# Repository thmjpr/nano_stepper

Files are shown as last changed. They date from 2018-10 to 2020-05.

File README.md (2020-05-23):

# Notes
This is a modication of the nano zero stepper.

Hardware changes

Rev 1:
- Board re-layout
- Connectors optimized for simplicity/cost
- Input protection added (fuse and TVS)
- 12-36V step down section added
- Inputs are over/under voltage protected (high = 2~24V). No external supply connection needed (w/ level shifter). Tested to 90kHz step speed, limited by firmware. Not opto.
- Error out open collector

Rev 2:
- Add motor voltage monitor analog input (0 to 33V range)
- Add NTC resistor to measure motor driver temperature
- Remove JTAG header
- Adjust switch footprint

Rev 3:
- Change motor driver to A4950
- Change micro to SAMD51G18A
- Nema17/23 layouts
- Remove unused parts

# Photos

Rev2:



Rev1:
board
board2

Original project:

# Smart Stepper (also known as the nano zero stepper)
Firmware to turn a stepper motor into servo motor: see http://misfittech.net for hardware! 

If you want to support the work on the firmware and hardware consider buying hardware from www.misfittech.net or buying me a beer using the donation button. 



# How to Install 
[Hardware install](http://misfittech.net/2016/11/29/installing-the-nano-zero-stepper/)

[Arduino install] (http://misfittech.net/2016/07/27/arduino_install/) for building firmware

[Further Details and to purchase Hardware] (http://misfittech.net/product/nano-zero-stepper/)

# Command List

## Smart Stepper Command Line Interface
The smart stepper uses a command line interface where the prompt is “:>” 

### help 
The help command will return a list of commands that the smart stepper supports. 

### getcal
This command will print out the 200 point calibration table.  This is useful if you are doing firmware development and do not want to calibrate each time you update firmware.  You can take this table and copy it into the nonvolatile.cpp file as shown below

### calibrate
This will run a 200 point calibration of the encoder. 

### testcal 
This will test the calibration and report the maximum error in degrees. 

### step
This will move the motor one step clockwise, the step size is based on the current microstep setting.  To move the motor counterclockwise use “step 1”. To move the motor clockwise 16 steps used “step 0 16” to move motor counterclockwise 16 steps use “step 1 16”

### feedback 
This commands disable/enables feedback control loop. 
The plan is to discountinue this command in the future and use the “controlmode” command to put controller in open or one of the many closed loop operational modes. 

### readpos
Reads the current motor position and reports it as degrees.

### encoderdiag
This command will read and report the AS5047D internal registers for diagnostic purposes. 

### microsteps 
This command gets/sets the number of microsteps the smart stepper will use for the step command and the step pin.  The number of microsteps does not affect the resolution of the controller but rather how fine you can set the position. 

### spid
This command sets the Kp, Ki, and Kd terms for the simple positional PID controller. 

### ppid
This command sets the Kp, Ki, and Kd terms for the positional PID controller. 

### vpid
This command sets the Kp, Ki, and Kd terms for the velocity PID controller. 

### velocity 
This sets the velocity to rotate motor when unit is configured for velocity PID mode of operation. 

### boot
This command will put the microprocessor in the boot loader mode.  Alternatively this can be done by double pressing the reset button. 

### factoryreset 
This erases the calibration and other system and motor parameters such that unit is reset to the factory ship state.  After this command the unit will need to be calibrated to the motor again. 

### dirpin
This command sets which direction the motor will rotate when direction pin is pulled high. The direction pin is only sampled when the step pin has a rising edge. 
‘dirpin 0’ will set the motor to rotate clockwise when dir pin is high
‘dirpin 1’ will set the motor to rotate counter-clockwise when dir pin is high

### errorlimit
Gets set the maximum number of degrees of error that is acceptable, any posistioning error about the error limit will assert the error pin, when error pin is set as error output. 
For example:
:>errorlimit 1.8 
Will set the error limit to 1.8 degrees. 

### ctrlmode
Gets/Sets the feedback controller mode of operation. The command takes an integer from 0 through 4 to set the control mode per table below:
Controller off - 	0  -- this is not currently used
Open-Loop - 	1  -- this is open loop with no feedback
Simple PID -   2  -- simple positional PID, which is factory default 
Positional PID - 3 -- current based PID mode, requires tuning for your machine
Velocity PID - 4 -- velocity based PID, requires tuning for your machine and speed range

If you are unsure what you are doing leave unit in the Simple PID mode of operation. 

### maxcurrent
This sets the maximum current that will be pushed into the motor. To set the current for maximum of 2.0A you would use command “maxcurrent 2000” as the argument is in milliAmps. 

### holdcurrent
For the Simple Positional PID mode the minimal current (ie current with no positional error) is the hold current. You set this current based on the required holding torque you need for your application. The higher the hold current, the hotter and noisier the motor will be but also the larger the holding torque. 
For the Positional PID mode the PID tuning params have to be set correctly such that the control loop will dynamically determine the holding torque. This tuning of the PID can be difficult, hence the simple PID mode will work most of the time out of the box by setting maximum current and holding current. 

### motorwiring
The firmware always uses a positive angle as a clockwise rotation. A stepper motor however could have wiring done with one coil reversed wired, which will cause motor to normally operate in opposite direction. The Smart Stepper firmware will detect the motor wiring direction, using the encoder, and the firmware will compensate for a reverse wired motor.  The reverse or forward wiring of a motor is detected on first power up after factory reset. If the wiring changes after that you can compensate using this command. 
HOWEVER  it is better to do a factory reset and recalibrate motor if wiring changes. 

### stepsperrotation
The Smart Stepper firmware will with first power on after factory reset detect the number of full steps per rotation for the stepper motor and store in flash memory. This command will read this parameter from flash and allow user to change this parameter if motor is changed.
HOWEVER  it is better to do a factory reset and recalibrate motor if motorchanges. 

### move
The move command will request the motor to move to an absolute angle position.  Optionally the user can specify the rotational speed (RPMs) by which the move should happen. For example if the current motor position is at angle 0 and you issue ‘move 3600” the motor will turn 10 rotations clockwise to angle of 3600 degrees. If issue the ‘move 3600’ again nothing will happen as motor is already at angle 3600. 
If motor is at angle 0 and user issues the command ‘move 3600 20’ then motor will move to 10 rotations clockwise to angle of 3600 at a rate of 20 RPMs. 

### stop
If user issues a move command that takes a long time and wants to stop the move before completion then user can issue the stop command command which will stop a move operation. 

### setzero
This command will take the current motor position and set it to absolute angle of  zero. Note that if you are in the middle move it will take the position at the time of the command and use it, thus it is recommend a move be stopped or wait for completion before issuing the setzero. 

## License:
All nano stepper related materials are released under the Creative Commons Attribution Share-Alike 4.0 License
Much of the work is based on Mechaduino project:
https://github.com/jcchurch13/Mechaduino-Firmware

This firmware also runs on the Mechaduino hardware and has many improvements over stock Mechaduino firmware. 
Note the Mechaduino 0.1 does have a few hardware issues that the firmware can not fix:

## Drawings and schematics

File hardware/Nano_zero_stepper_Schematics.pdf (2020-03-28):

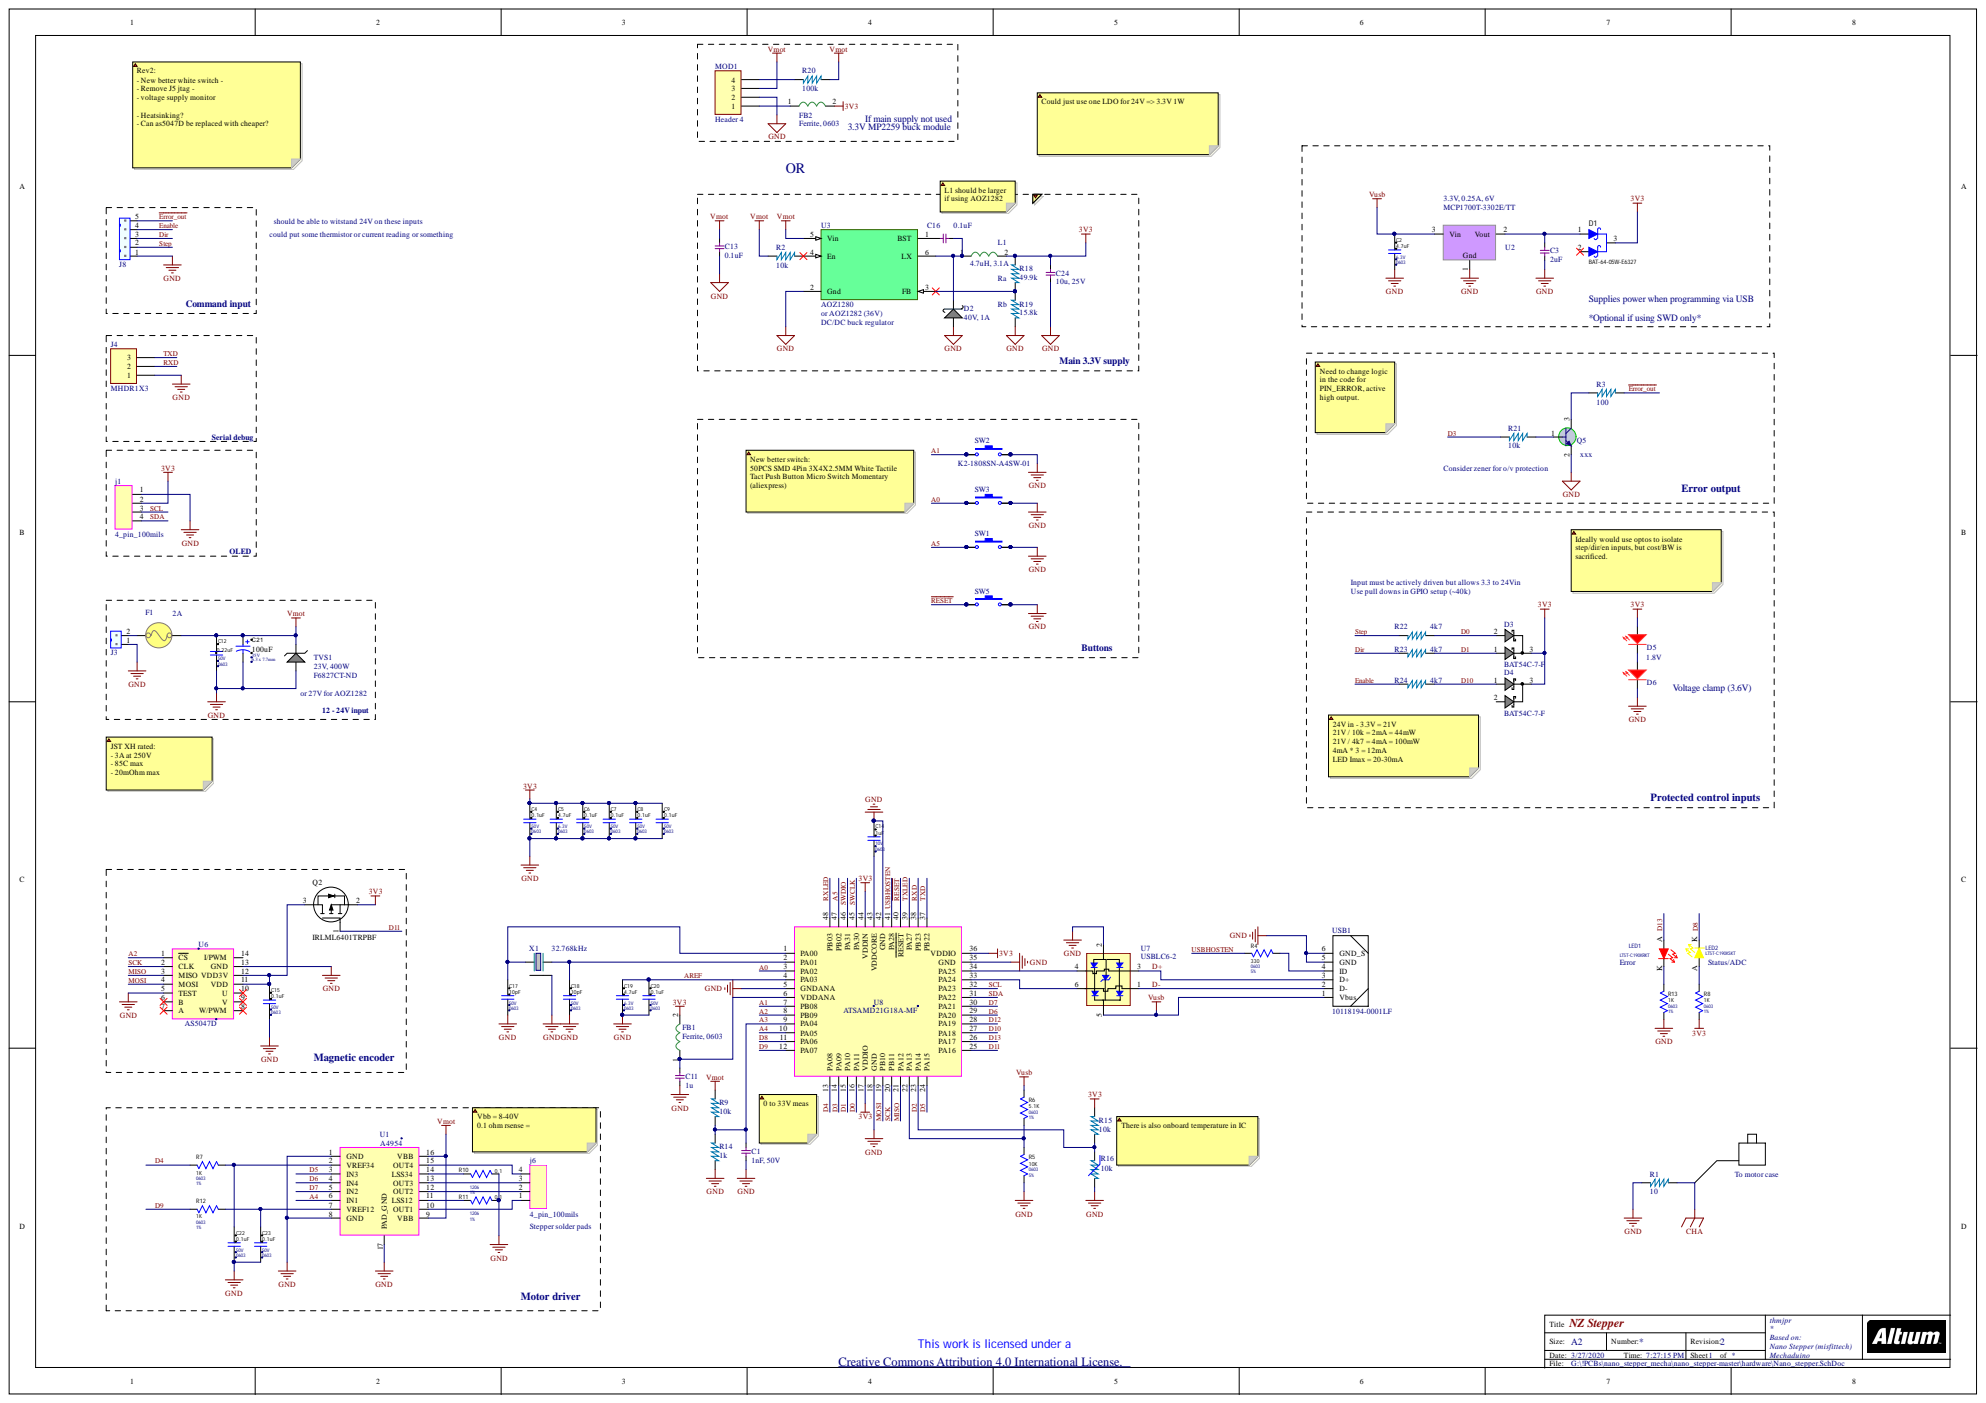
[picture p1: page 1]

Rev2:
- New better white switch -
- Remove J5 jtag -
- voltage supply monitor

Could just use one LDO for 24V => 3.3V 1W

- Heatsinking?
- Can as5047D be replaced with cheaper?

Error_out
should be able to witstand 24V on these inputs Enable

could put some thermistor or current reading or something

Supplies power when programming via USB

*Optional if using SWD only*

Need to change logic
in the code for
PIN_ERROR, active
high output.

New better switch:
50PCS SMD 4Pin 3X4X2.5MM White Tactile
Tact Push Button Micro Switch Momentary
(aliexpress)

Consider zener for o/v protection

Ideally would use optos to isolate
step/dir/en inputs, but cost/BW is
sacrificed.

Input must be actively driven but allows 3.3 to 24Vin
Use pull downs in GPIO setup (~40k)

36 B22 37 PB23 38 PA27 39 RESET 40 PA28 41 GND 42 VDDCORE 43 VDDIN 44 PA30 45 PA31 46 PB02 47 PB03 48

There is also onboard temperature in IC

NZ Stepper Title | thmjpr * Based on: Nano Stepper (misfittech) Mechaduino

This work is licensed under a

Size: A2 | Number: * | Revision: 2
Date: 3/27/2020 Time: 7:27:15 PM | | Sheet 1 of *

Creative Commons Attribution 4.0 International License. (http://creativecommons.org/licenses/by/4.0/)

G:\!PCBs\nano_stepper_mecha\nano_stepper-master\hardware\Nano_stepper.SchDoc

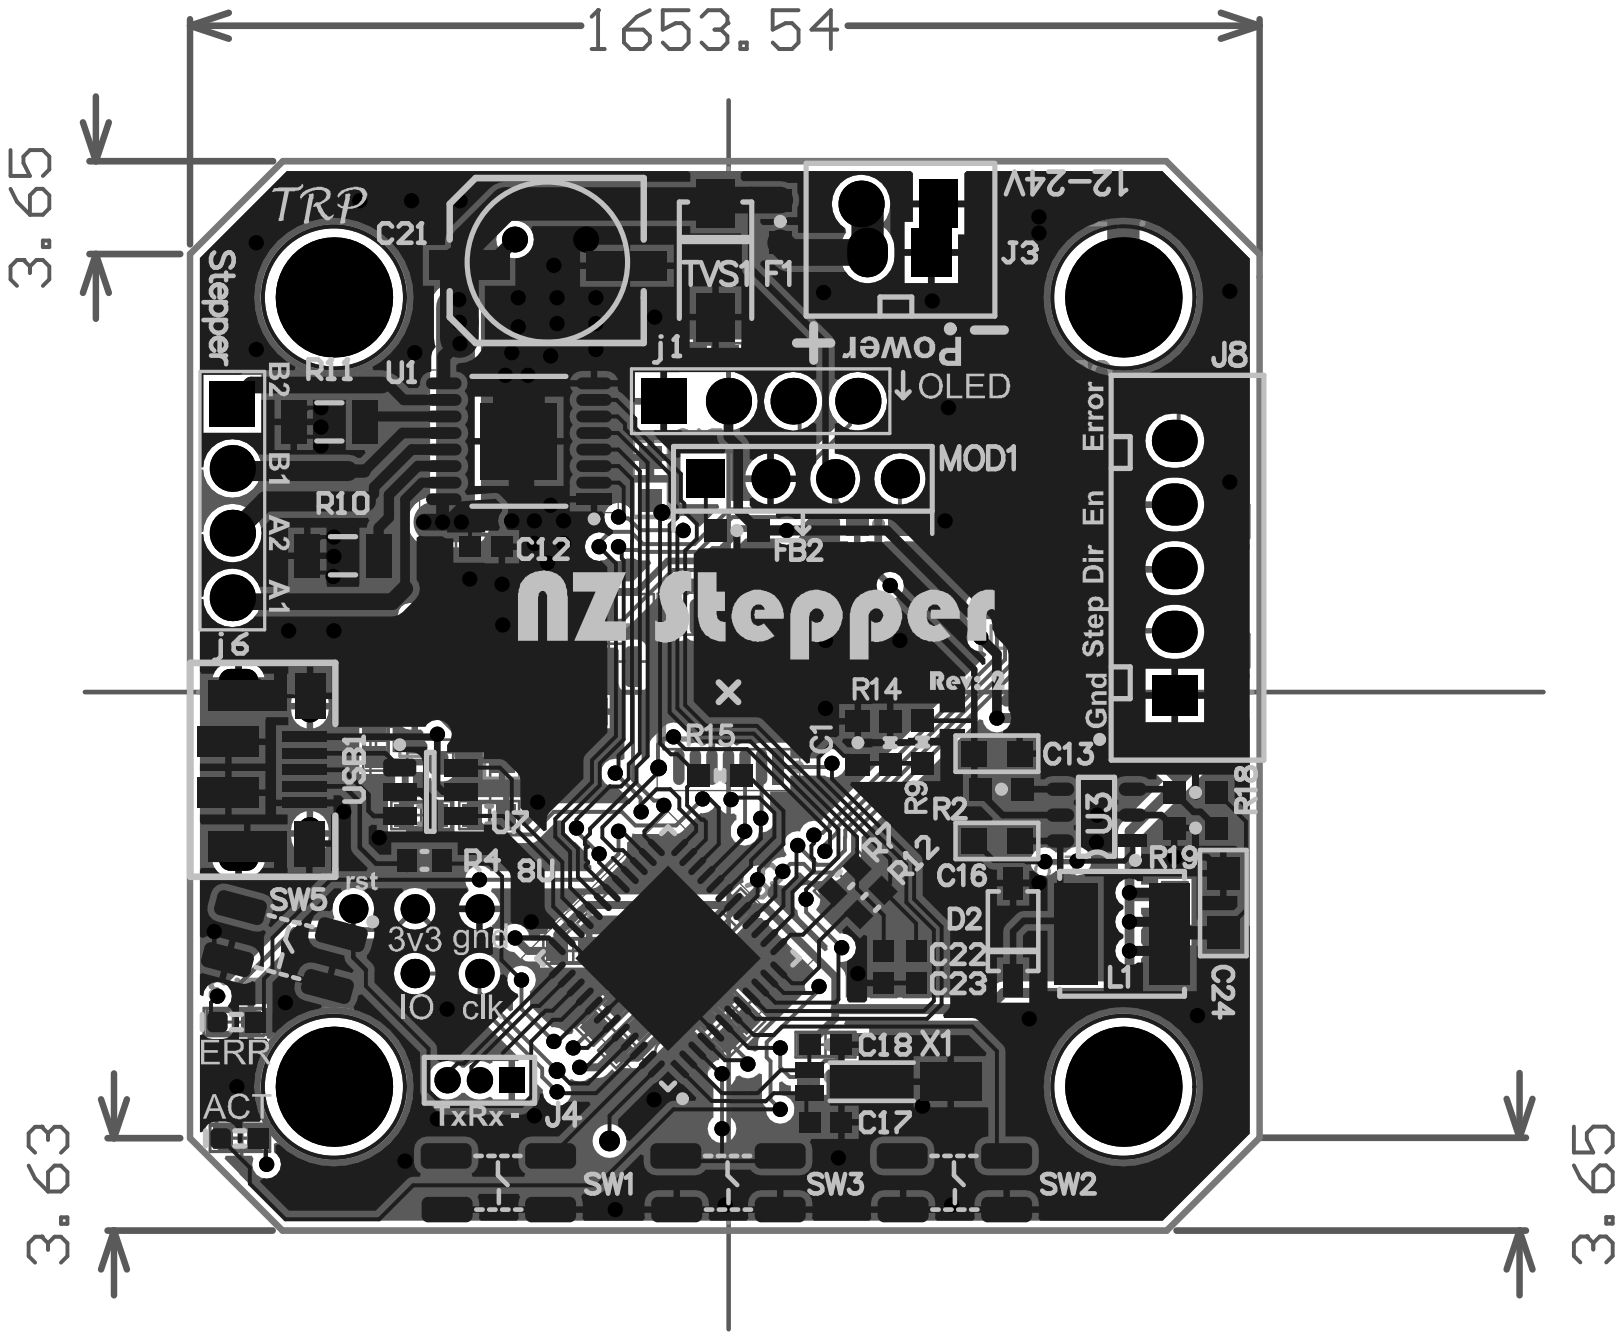
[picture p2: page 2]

Comment | Description | Designator | Footprint | LibRef | Quantity | Manufacturer_PartMisfitPri ce
CAP-NP | CAP, XXX, 50V, NPOC1 | | 0603_CAP_no oveCAP-NP | | 1
4.7uF | CAP 0603 CER 4.7UC2,C5, C19 | | CAP_0603_H | altiumdb4ee8d107ce | 3 | JMK107BJ475KA-T0
CAP-NP | CAP, XXX, 50V, NPOC3, C13, C16 | | 0603_cap | CAP-NP | 3
0.1uF | CAP CER 0.1UF 50VC4,C6, C7, C8, C9,CAP_0603 _H | | | altiumdb529bf947b98393. | 9 | CL10F104ZB8NNN0
CAP-NP | CAP, XXX, 50V, NPOC11 | | 0603 - no overlay | CAP-NP | 1
0.22uF | CAP CER 0.1UF 50VC12 | | CAP_0603_H | altiumdb529bf947b98393. | 1 | CL10F104ZB8NNN0
1uF | CAP 0603 CER 1UFC 14 | | CAP_0603_H | altiumdb4ee8b0b72e | 1 | C0603C105K8PAC0
10pF | CAP 0603 CER 10PFC17, C18 | | CAP_0603_H | altiumdb4ee8b063d08416. | 2 | C0603C100J5GAC0
100uF | 100uF 35V SMD | C21 | UWT1V101MCL1GSaltiumdb57a880e8344183. | | 1 | UWT1V101MCL1G0
CAP-NP | CAP, XXX, 50V, NPOC24 | | 0805 | CAP-NP | 1
BAT-64-05W-E632DIODE SCHOTTKYD 1 | | | BAT-64-05W-E632altiumdb4f1b209379f | | 1 | BAT64-05W H63270
x | Diode, XXA, XXV, SD2 | | SOD-123 | DIODE-SCHOTTKY | 1
BAT54C | Diode, 200mA, 30VD3,D 4 | | SOT-23 | DIODE-BAT54C-7- | 2
04-060001-011 | LED, Red, 12.7mcd,D5,D6 | | 0603_diode | LED-Red | 2
FUSE_SRF | Fuse, SRF, ?A, ?VDF1 | | 0603 | FUSE_SRF | 1
IND | Inductor, XXuH, XXFB1,FB2 | | 0603 - no overlay | IND | 2
4_pin_100mils | | j1, j6 | 4_pin_100mils | altiumdb50250c9a | 2 | 4_pin_100mils | 0
JST_XH_Male_2 | CON, Pol-Lock MaJ3 | | JST_B2B_XH_A | JST_XH_Male_2 | 1
MHDR1X3 | Header, 3-Pin | J4 | MHDR1X3 | MHDR1X3 | 1
JST_XH_Male_5 | CON, Pol-Lock MaJ8 | | JST_B5B_XH_A | JST_XH_Male_5 | 1
NR5040 | Inductor, 4.7uH, 3.L1 | | NR5040 | Ind1 | 1
LTST-C190KRKT | LED SUPER RED CD1 | | LTST-C 190KRKT | altiumdb4f59f5b2e | 1 | LTST-C190KRKT | 0
LTST-C190KSKT | LED YELLOW CLEALED 2 | | LTST-C190KSKT | altiumdb52dbc15523a | 1 | LTST-C190KSKT | 0
Header 4 | Header, 4-Pin | MOD1 | HDR1X4 | Header 4 | 1
IRLML6401TRPBF MOSFETP-CH12VQ2 | | | IRLML6401TRPBF_altiumdb4f097f24c87689. | | 1 | IRLML6401TRPBF 0.0781
TRANS-BJT-NPN | TRANS, BJT,NPN, Q5 | | SOT-23 | TRANS-BJT-NPN | 1
RES | RES, XXX, 1/10W,R1 | | 0805 | RES | 1
RES | RES, XXX, 1/10W,R2, R 3,R18,R19, 0603 - n o ove rlay | | | RES | 9
330 | RES 0603 TKF 330RR4 | | RES_0603_H | altiumdb4ee8dc965f | 1 | RC0603JR-07330R0
10K | RES 0603 TKF 10KR5 | | RES_0603_H | altiumdb4ee8dc331cbc98. | 1 | RC0603JR-0710KL0
5.1K | RES 0603 TKF 5.1KR6 | | RES_0603_H | altiumdb4ee8dcacc79f | 1 | CRCW06035K10FK0
1K | RES 0603 TKF 1K | R7, R8,R12, R13 | RES_0603_H | altiumdb4ee8dc53e | 4 | CRCW06031K00F0
RES | RES, XXX, 1/10W,R9,R14, R15 | | 0603_re s_no_overRES | | 3
0.1 | RES 0.2 OHM 0.25W R10,R1 1 | | RES_1206_H | altiumdb52db39dc769f | 2 | PT1206FR-070R2L0
RES-NTC | Therm, NTC, XXk,R1 6 | | 0603_res | RES-NTC | 1
SW-PB-SPST_smaS witch, PB, SPST-NSW1, SW2, SW3, SS W-PB -K2-1808SNSW-PB -SPST_sma | | | | | 4
F6827CT-ND | TVS, ?V, ?W, UnidiTVS1 | | SMA | TVS_UNI | 1
A4954 | | U1 | A4954 | altiumdb57cf0e2bc99638. | 1 | A4954 | 0
IC-MCP1700 | IC, Reg LDO, 250mU2 | | SOT-23 | IC-MCP1700T-500 | 1
AOZ1280 | IC, Buck regulator,U 3 | | SOT23-6L | AOZ1280 | 1
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

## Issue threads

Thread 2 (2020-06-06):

TMC2209 noob question

froust-company, 2020-06-06:
Hi

Is it possible to just add tmc2209 to the board without major firmware modification?

Regards

thmjpr, 2021-02-11:
Board would need redesign and quite a few software changes.

Closed 2021-02-11.

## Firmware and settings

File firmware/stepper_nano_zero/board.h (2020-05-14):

/**********************************************************************
 *      Author: tstern
 *
 *	Misfit Tech invests time and resources providing this open source code,
 *	please support Misfit Tech and open-source hardware by purchasing
 *	products from Misfit Tech, www.misifittech.net!
 *
 *	Written by Trampas Stern for Misfit Tech.
 *	BSD license, check license.txt for more information
 *	All text above, must be included in any redistribution
 *********************************************************************/
#ifndef __BOARD_H__
#define __BOARD_H__

#include <Arduino.h>

//Debugging notes:
//- Jlink - turn off "flash caching " in JLINK settings

//Board type used
#define NZ_STEPPER_REV2
//#define MECHADUINO_HARDWARE	//uncomment this if you are using the Mechaduino hardware
//#define NEMA_23_10A_HW 		//uncomment the follow lines if using the NEMA 23 10A hardware
#define DEBUG 1


//Optimizations
#define NZS_FAST_CAL			//define this to use 32k of flash for fast calibration table
#define NZS_FAST_SINE			//uses 2048 extra bytes to implement faster sine tables
#define NZS_AS5047_PIPELINE		//does a pipeline read of encoder, which is slightly faster 
#define NZS_CONTROL_LOOP_HZ (5000)	//(6000) //update rate of control loop  **FF need to check what performance is affected

#define NZS_LCD_ABSOLUTE_ANGLE  //define this to show angle from zero in positive and negative direction
								// for example 2 rotations from start will be angle of 720 degrees

//#define ENABLE_PHASE_PREDICTION //this enables prediction of phase at high velocity to increase motor speed
//as of FW0.11 it is considered development only

#define BUILD_DATE __DATE__		//Build date, 11 char long
#define VERSION "FW: 0.40"		//this is what prints on LCD during splash screen

//Define this to allow command out serial port, else hardware serial is debug log
//#define CMD_SERIAL_PORT
#define SERIAL_BAUD (115200)	//baud rate for the serial ports		//jlink max = 128k

//This section is for using the step and dir pins as serial port
// when the enable pin is inactive.
//#define USE_STEP_DIR_SERIAL
//#define STEP_DIR_BAUD (19200) //this is the baud rate we will use

// These are used as an attempt to use TC4 to count steps
//  currently this is not working.
//#define USE_NEW_STEP //define this to use new step method
#define USE_TC_STEP		//use timer counter for step pin

#ifndef F_CPU
	#define F_CPU (48000000UL)
#endif

/* TODO are flaged with TODO
 *   TODO - add detection of magnet to make sure PCB is on motor
 *   change BOD interrupt to ? use motor voltage dropping instead?
 */
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

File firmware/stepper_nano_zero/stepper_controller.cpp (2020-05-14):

/**********************************************************************
 *      Author: tstern
 *
 *	Misfit Tech invests time and resources providing this open source code,
 *	please support Misfit Tech and open-source hardware by purchasing
 *	products from Misfit Tech, www.misifittech.net!
 *
 *	Written by Trampas Stern  for Misfit Tech.
 *	BSD license, check license.txt for more information
 *	All text above, must be included in any redistribution
 *********************************************************************/
#include "stepper_controller.h"
#include "nzs_lcd.h"
#include "adc_analog.h"
#include "nonvolatile.h"		//for programmable parameters
#include <Wire.h>
#include <inttypes.h>
#include "steppin.h"

#pragma GCC push_options
#pragma GCC optimize ("-Ofast")

#define WAIT_TC16_REGS_SYNC(x) while(x->COUNT16.STATUS.bit.SYNCBUSY);
#define n16_BIT_MAX		65536
static_assert((100 < (F_CPU / NZS_CONTROL_LOOP_HZ)) & ((F_CPU / NZS_CONTROL_LOOP_HZ) < n16_BIT_MAX), "control loop frequency bad");

volatile bool TC5_ISR_Enabled = false;
extern ADC_Peripheral adc;

void setupTCInterrupts()
{
	// Enable GCLK for TC4 and TC5 (timer counter input clock)
	GCLK->CLKCTRL.reg = (uint16_t)(GCLK_CLKCTRL_CLKEN | GCLK_CLKCTRL_GEN_GCLK0 | GCLK_CLKCTRL_ID(GCM_TC4_TC5));
	while (GCLK->STATUS.bit.SYNCBUSY);

	TC5->COUNT16.CTRLA.bit.ENABLE = 0;									// Disable TCx
	//TC5->COUNT16.CTRLA.bit.SWRST = 1; 									// Reset Timer
	TC5->COUNT16.CTRLA.bit.MODE = TC_CTRLA_MODE_COUNT16_Val;			// Set Timer counter Mode to 16 bits
	TC5->COUNT16.CTRLA.bit.WAVEGEN = TC_CTRLA_WAVEGEN_MFRQ_Val;			// Set TC as normal Normal Frq
	TC5->COUNT16.CTRLA.bit.PRESCALER = TC_CTRLA_PRESCALER_DIV1_Val;		// Set prescaler - none
	TC5->COUNT16.CC[0].reg = (F_CPU / NZS_CONTROL_LOOP_HZ);				//Set capture channel interrupt, 48MHz/6000Hz 0.2ms
	WAIT_TC16_REGS_SYNC(TC5)
		
	//TC5->COUNT16.DBGCTRL.bit.DBGRUN = 0;		//Run timer when debug stopped yes (1) or no (0)
	TC5->COUNT16.INTENSET.reg = 0;              // disable all interrupts
	//TC5->COUNT16.INTENSET.bit.OVF = 1;          // enable overflow interrupt
	TC5->COUNT16.INTENSET.bit.MC0 = 1;         // enable compare match to CC0
	WAIT_TC16_REGS_SYNC(TC5)
		
	//Interrupt
	NVIC_ClearPendingIRQ(TC5_IRQn);				//Clear any pending
	NVIC_SetPriority(TC5_IRQn, 2);				//Set priority of interrupt to lowest
	NVIC_EnableIRQ(TC5_IRQn);					//Enable InterruptVector
	
	TC5->COUNT16.CTRLA.bit.ENABLE = 1; 			//Enable timer TCx
}

static void enableTCInterrupts()
{
	TC5_ISR_Enabled = true;
	NVIC_EnableIRQ(TC5_IRQn);
	TC5->COUNT16.INTENSET.bit.MC0 = 1;		//set compare match
}

static void disableTCInterrupts()
{
	TC5_ISR_Enabled = false;
	//NVIC_DisableIRQ(TC5_IRQn);
	TC5->COUNT16.INTENCLR.bit.MC0 = 1;		//clear compare match
}

static bool enterCriticalSection()
{
	bool state = TC5_ISR_Enabled;
	disableTCInterrupts();
	return state;
}

static void exitCriticalSection(bool prevState)
{
	if (prevState)
	{
		enableTCInterrupts();
	} //else do nothing
}

void StepperCtrl::updateParamsFromNVM(void)
{
	bool state = enterCriticalSection();

	pPID.Kd = NVM->pPID.Kd * CTRL_PID_SCALING;
	pPID.Ki = NVM->pPID.Ki * CTRL_PID_SCALING;
	pPID.Kp = NVM->pPID.Kp * CTRL_PID_SCALING;

	vPID.Kd = NVM->vPID.Kd * CTRL_PID_SCALING;
	vPID.Ki = NVM->vPID.Ki * CTRL_PID_SCALING;
	vPID.Kp = NVM->vPID.Kp * CTRL_PID_SCALING;

	sPID.Kd = NVM->sPID.Kd * CTRL_PID_SCALING;
	sPID.Ki = NVM->sPID.Ki * CTRL_PID_SCALING;
	sPID.Kp = NVM->sPID.Kp * CTRL_PID_SCALING;

	if (NVM->SystemParams.parametersValid)
	{
		memcpy((void *)&systemParams, (void *)&NVM->SystemParams, sizeof(systemParams));
		LOG("Home pin %d", systemParams.homePin);
	}
	else
	{
		ERROR("This should never happen but just in case");
		systemParams.microsteps = 256;
		systemParams.controllerMode = feedbackCtrl::SIMPLE;
		systemParams.dirPinRotation = RotationDir::CW; //default to clockwise rotation when dir is high
		systemParams.errorLimit = (int32_t)ANGLE_FROM_DEGREES(1.8);
		systemParams.errorPinMode = ErrorPinMode::ACTIVE_LOW; //active low on error (open collector on)
		systemParams.enablePinMode = EnablePinMode::ALWAYS_ON;
		systemParams.errorLogic = false;
		systemParams.homeAngleDelay = ANGLE_FROM_DEGREES(10);
		systemParams.homePin = -1; //no homing pin configured
	}

	//default the error pin to input, if it is an error pin the
	// handler for this will change the pin to be an output.
	// for bidirection error it has to handle input/output it's self as well.
	// This is not the cleanest way to handle this...
	pinMode(PIN_ERROR, INPUT_PULLUP); //we have input pin **FF

	if (NVM->motorParams.parametersValid)
	{
		memcpy((void *)&motorParams, (void *)&NVM->motorParams, sizeof(motorParams));
	}
	else
	{
		LOG("setting default mparam");
		//MotorParams_t Params;
		motorParams.fullStepsPerRotation = 200;
		motorParams.currentHoldMa = 400;
		motorParams.currentMa = 600;
		motorParams.homeHoldMa = 500;
		motorParams.homeMa = 500;
		motorParams.motorWiring = true;
		//memcpy((void *)&Params, (void *)&motorParams, sizeof(motorParams));
		//nvmWriteMotorParms(Params);
	}
	stepperDriver.setRotationDirection(motorParams.motorWiring);
	exitCriticalSection(state);
}

void  StepperCtrl::motorReset(void)
{
	//when we reset the motor we want to also sync the motor
	// phase.  Therefore we move forward a few full steps then back
	// to sync motor phasing, leaving the motor at "phase 0"
	bool state = enterCriticalSection();

	//	stepperDriver.move(0,motorParams.currentMa);
	 //	stepperDriver.move(0,motorParams.currentMa);
	 //	delay(100);
	 //	stepperDriver.move(A4954_NUM_MICROSTEPS,motorParams.currentMa);
	 //	delay(100);
	 //	stepperDriver.move(A4954_NUM_MICROSTEPS*2,motorParams.currentMa);
	 //	delay(100);
	 //	stepperDriver.move(A4954_NUM_MICROSTEPS*3,motorParams.currentMa);
	 //	delay(100);
	 //	stepperDriver.move(A4954_NUM_MICROSTEPS*2,motorParams.currentMa);
	 //	delay(100);
	 //	stepperDriver.move(A4954_NUM_MICROSTEPS,motorParams.currentMa);
	 //	delay(100);
	stepperDriver.move(0, motorParams.currentMa);
	delay(1000);

	setLocationFromEncoder(); //measure new starting point
	exitCriticalSection(state);
}
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

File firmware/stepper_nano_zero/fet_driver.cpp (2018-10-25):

/*
 * fet_driver.cpp
 *
 *  Created on: Dec 24, 2016
 *      Author: tstern
 *
 * This file supports using discrete FETs as drivers for stepper motor
 *
 *	Misfit Tech invests time and resources providing this open source code,
 *	please support Misfit Tech and open-source hardware by purchasing
 *	products from Misfit Tech, www.misifittech.net!
 *
 *	Written by Trampas Stern  for Misfit Tech.
 *	BSD license, check license.txt for more information
 *	All text above, must be included in any redistribution
 *********************************************************************/
#include "fet_driver.h"
#include "wiring_private.h"
#include "syslog.h"
#include "angle.h"
#include "Arduino.h"
#include "sine.h"
#include "nonvolatile.h"

#pragma GCC push_options
#pragma GCC optimize ("-Ofast")

#ifdef NEMA_23_10A_HW

#define FET_DRIVER_FREQ  (46875UL) //FET PWM pin driver frequency

FetDriver *FetDriver::ptrInstance=0;

// Wait for synchronization of registers between the clock domains
static __inline__ void syncDAC() __attribute__((always_inline, unused));
static void syncDAC() {
	while (DAC->STATUS.bit.SYNCBUSY == 1)
		;
}


volatile uint32_t coilA_Value=0;
/*
 *  The discrete FETs on the NEMA 23 10A board are configured such that each H-bridge has:
 *    IN1 - Input 1
 *    IN2 - Input 2
 *    Enable - Enable driver
 *    Isense - current sense
 *
 *    The truth table for the H-Bridge is:
 *    Enable	IN1		IN2		Bridge State
 *    0			x		x		floating (FETs off)
 *    1			0		0		coil shorted to Gnd
 *    1			0		1		forward
 *    1			1		0		reverse
 *    1			1		1		coil shorted to VCC
 *
 *    For peak current control there is two state (fast decay, and slow decay)
 *
 *    Fast Decay
 *    When driving coil in forward direction and current peak is reached the fast decay turns
 *    The bridge in the reverse direction. This cause the reverse EMF from coil to charge
 *    capacitors back up and the current on the coil to drop very quickly
 *
 *    Slow Decay
 *    During this mode the current decay is slower by shorting the coil leads to ground.
 *    This in effect shorts the coil leads and reverse EMF is converted to heat.
 *
 *    In the Fast Decay mode we reverse the motor, this in effect is trying to drive coil
 *    current in the reverse direction. This in effect reduces current faster than just
 *    shorting the coil out.
 *
 *    see www.misfittech.net's blog for more information on this subject
 *
 */

/* driver code's logic
 *
 * 	This driver code needs not only to control the FETs but also handle the current limits.
 *
 * 	The way the code handles limiting current is by using two comparators internal to
 * 	the microprocessor.
 *
 * 	We first use two PWM signals to generate reference voltage for each comparator.
 * 	Then when the current sense voltage exceeds this reference voltage an interrupt is
 * 	generated. In the interrupt handler we will then set the decay mode as needed.
 *
 * 	It will have to be determined if we will use a fixed time decay mode like the A4954,
 * 	or use current as the threshold. There is a lot to do here to maintain quite operation,
 * 	that is we need this current control to be running at more than 20khz to be quite.
 *
 * 	Additionally we can use ADC on the current sense for detecting the flyback and
 * 	get some idea of the inductance. This can be used for stall dection as well as
 * 	auto tuning of some of the driver parameters.
 */



#pragma GCC push_options
#pragma GCC optimize ("-Ofast")

#define WAIT_TC16_REGS_SYNC(x) while(x->COUNT16.STATUS.bit.SYNCBUSY);

typedef enum {
	CURRENT_ON = 0,
	CURRENT_FAST_DECAY = 1,
	CURRENT_SLOW_DECAY = 2,
} CurrentMode_t;

typedef enum {
	COIL_FORWARD =0,
	COIL_REVERSE =1,
	COIL_BRAKE =2
} CoilState_t;

typedef struct {
	bool currentIncreasing; //true when we are increasing current
	CurrentMode_t currentState; //how is bridge driven
} BridgeState_t;

volatile BridgeState_t BridgeA, BridgeB;


#define DAC_MAX (0x01FFL)
// Wait for synchronization of registers between the clock domains
static __inline__ void syncTCC(Tcc* TCCx) __attribute__((always_inline, unused));
static void syncTCC(Tcc* TCCx) {
	//int32_t t0=1000;
	while (TCCx->SYNCBUSY.reg & TCC_SYNCBUSY_MASK)
	{
		//		t0--;
		//		if (t0==0)
		//		{
		//			break;
		//		}

	}
}





static inline void coilA(CoilState_t state)
{
	PIN_GPIO_OUTPUT(PIN_FET_IN1);
	PIN_GPIO_OUTPUT(PIN_FET_IN2);
	switch(state){

		case COIL_FORWARD:
			GPIO_HIGH(PIN_FET_IN1);
			GPIO_LOW(PIN_FET_IN2);
			break;

		case COIL_REVERSE:
			GPIO_HIGH(PIN_FET_IN2);
			GPIO_LOW(PIN_FET_IN1);
			break;

		case COIL_BRAKE:
			GPIO_LOW(PIN_FET_IN2);
			GPIO_LOW(PIN_FET_IN1);
			break;

		default:
			ERROR("Not a known state");
			break;
	}

}

static inline void coilB(CoilState_t state)
{
	PIN_GPIO_OUTPUT(PIN_FET_IN3);
	PIN_GPIO_OUTPUT(PIN_FET_IN4);
	switch(state){
		case COIL_FORWARD:
			GPIO_HIGH(PIN_FET_IN3);
			GPIO_LOW(PIN_FET_IN4);
			break;

		case COIL_REVERSE:
			GPIO_HIGH(PIN_FET_IN4);
			GPIO_LOW(PIN_FET_IN3);
			break;

		case COIL_BRAKE:
			GPIO_LOW(PIN_FET_IN3);
			GPIO_LOW(PIN_FET_IN4);
			break;

		default:
			ERROR("Not a known state");
			break;
	}
}


int FetDriver::coilA_PWM(int32_t value)
{
	int32_t x;
	// PIN_FET_IN1	 (PA15)		(5)  (TCC0 WO[5], aka ch1)
	//PIN_FET_IN2    (PA20)		(6)  (TCC0 WO[6], aka ch2)
	Tcc* TCCx = TCC0 ;

//
//	if (value==0)
//	{
//		GPIO_LOW(PIN_FET_IN1);
//		GPIO_LOW(PIN_FET_IN2);
//		PIN_GPIO(PIN_FET_IN1);
//		PIN_GPIO(PIN_FET_IN2);
//		return;
//	}

	if (value<0)
	{
		GPIO_LOW(PIN_FET_IN1);
		PIN_GPIO(PIN_FET_IN1);
		PIN_PERIPH(PIN_FET_IN2);
		//pinPeripheral(PIN_FET_IN2, PIO_TIMER_ALT); //TCC0 WO[7]
		value=-value;
	}else
	{
		GPIO_LOW(PIN_FET_IN2);
		PIN_GPIO(PIN_FET_IN2);
		PIN_PERIPH(PIN_FET_IN1);
		//pinPeripheral(PIN_FET_IN1, PIO_TIMER_ALT);
	}


#if (F_CPU/FET_DRIVER_FREQ)==1024
	x=value & 0x3FF;
#else
	x=MIN(value, (int32_t)(F_CPU/FET_DRIVER_FREQ));
#endif

	syncTCC(TCCx);
	TCCx->CC[1].reg = (uint32_t)x; //ch1 == ch5 //IN3
	//syncTCC(TCCx);
	TCCx->CC[2].reg = (uint32_t)x; //ch2 == ch6 //IN4
	if (x!=value)
	{
		return 1;
	}
	return 0;

}

void FetDriver::coilB_PWM(int32_t value)
{

	//PIN_FET_IN3	 (PA21)		(7)	 (TCC0 WO[7], aka ch3)
	//PIN_FET_IN4    (PA14)		(2)  (TCC0 WO[4], aka ch0)
	Tcc* TCCx = TCC0 ;


//
//	if (value==0)
//	{
//		GPIO_LOW(PIN_FET_IN3);
//		GPIO_LOW(PIN_FET_IN4);
//		PIN_GPIO(PIN_FET_IN3);
//		PIN_GPIO(PIN_FET_IN4);
//		return;
//	}


	if (value<=0)
	{
		GPIO_LOW(PIN_FET_IN3);
		PIN_GPIO(PIN_FET_IN3);
		PIN_PERIPH(PIN_FET_IN4);
		//SET_PIN_PERHERIAL(PIN_FET_IN4, PIO_TIMER_ALT); //TCC0 WO[7]
		value=-value;
	}else
	{
		GPIO_LOW(PIN_FET_IN4);
		PIN_GPIO(PIN_FET_IN4);
		PIN_PERIPH(PIN_FET_IN3);
		//SET_PIN_PERHERIAL(PIN_FET_IN3, PIO_TIMER_ALT);
	}
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

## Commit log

2017-07-21 - add dc/dc converter - add header for dc/dc module - change input to resistor clipped, instead of level shifter - re layout board - error out open collector - TVS motor voltage protection - change c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
    [NZS_A4954.PrjPcb, NZS_A4954_R2_0.PcbDoc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]
2017-11-20 - add splash screen image - add LCD message for calibration routine - add support for NZS hardware (minor difference in i/o)
2020-03-28 - Add rev 2 hardware files
    [NZS_A4954_Rx.GBL, NZS_A4954_Rx.GBO, NZS_A4954_Rx.GBP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]
2020-03-29 - adjust motor voltage read - motor temperature - menu item for info
2020-04-23 - separate enable and error pins
    [A4954.cpp, A5995.cpp, board.h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]
2020-05-04 - check flashErase ok - enable pin revert, dedicate to single use - update with 0.39 changes - minor changes
    [A4954.cpp, angle.h, as5047d.cpp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]
2020-05-10 - add adc_analog.cpp - add temp measurement (not working.. maybe hw issue) - SPI 5MHz -> 10MHz - stubs for no LCD - adjust BOD lower
    [A4954.cpp, A4954.h, adc_analog.cpp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]
2020-05-10 change TC5 interrupt to compare match
2020-05-14 - motor temperature seems to work - begin adding info settings page - add temperature/voltage to main screen
